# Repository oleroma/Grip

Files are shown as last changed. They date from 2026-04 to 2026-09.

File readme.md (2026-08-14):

<h1 align="center">
  <picture>
    <source media="(prefers-color-scheme: dark)" srcset="./media/logo_light.svg">
    <source media="(prefers-color-scheme: light)" srcset="./media/logo_dark.svg">
    <!-- The fallback image for older browsers -->
    Project Title
  </picture>
  <br>
</h1>

# GRIP
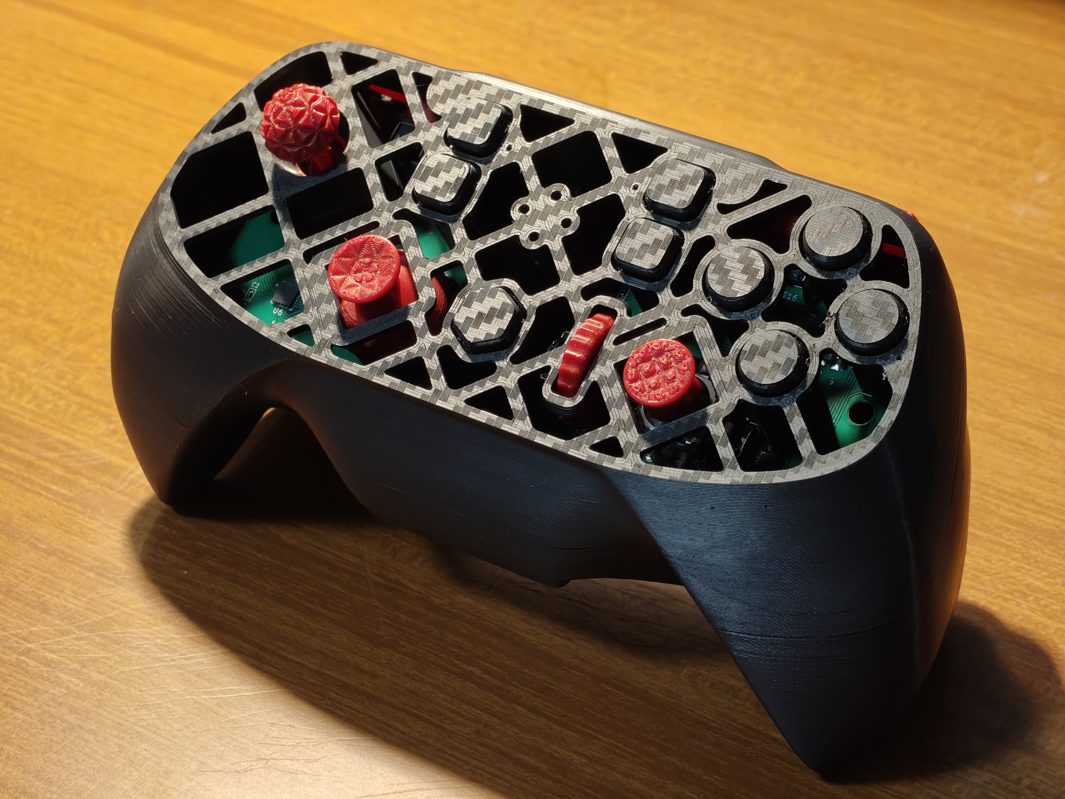
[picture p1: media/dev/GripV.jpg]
GripV


*(Work in progress... release coming soon)*

---

## **FEATURES AND PROGRESS**

### CASE SHAPES

The project will include the following **CASE SHAPES**: 
1. 2 smooth, classic shapes in Xbox and DualSense styles.
2. Custom ergonomic "pistol-like" shape.
3. SNES-style shape for portability (bonus shape).
4. Experimental custom ergonomic "pistol-like" shape with compliant bumpers L1R1 (will be released as experimental; currently exhibits cursor jumping).

> **NOTE:** You can easily swap the case for your own custom shape by placing your mesh into the corresponding "basemesh" collection—just drop it into the collection, and it will automatically be sliced and cut.

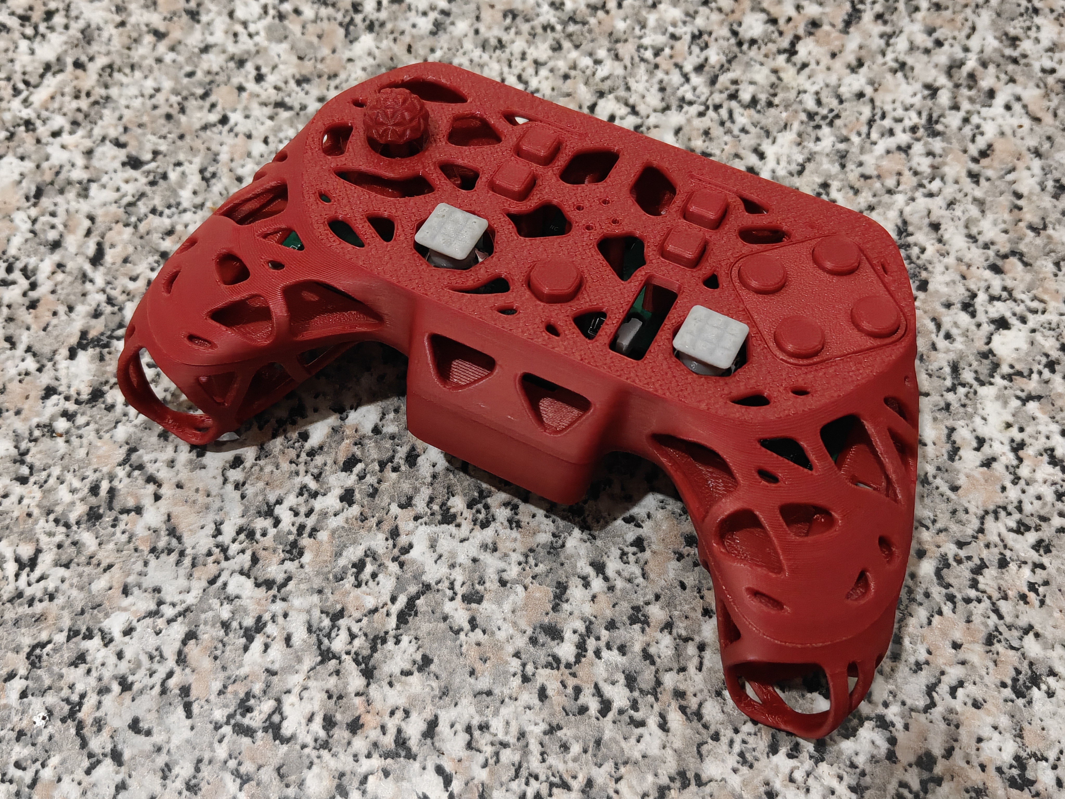
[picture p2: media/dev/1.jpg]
GripX


### HORIZONTALLY PRINTED BUTTONS

By default, the custom ergonomic shape (and possibly the classic shape) will use horizontally printed buttons with caps, as they provide a better feel, tighter tolerances, and less squeak. 

### FULL-SIZE RIGHT STICK

A great advantage of horizontal buttons is that when used with caps, their shafts are much smaller. Combined with a thinner scroll wheel and a new custom wheel support, this allows for a **FULL-SIZE RIGHT STICK** with a shield. This means you can have identical left and right sticks.

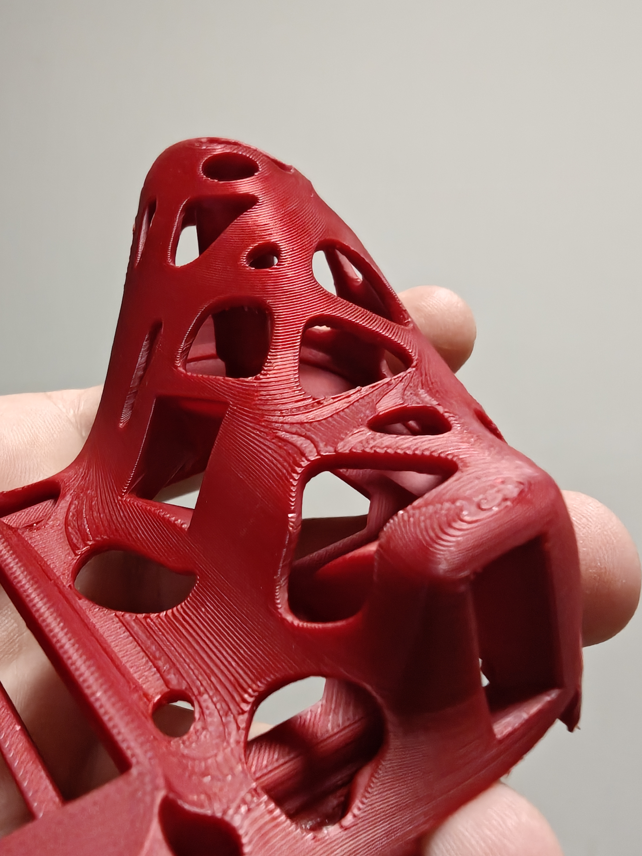
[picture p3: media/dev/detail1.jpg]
detail


### ADJUSTABLE TRIGGERS

Arch shaped triggers for L2R2 L4R4 do not require any screws to work and can be adjusted to fit different hands.

### **PROCEDURAL SHELL OPTIONS**

All shapes will come with an optional "hollow" version (made using Signed Distance Fields, or SDFs) that can be either a shell-like structure or a lattice-like structure with holes.

* **Hollow Version:** A 3-part assembly consisting of a top case, a bottom case, and a middle plate that holds the PCB. 
* **Solid Version:** Includes optional grip texturing featuring **periodic surface patterns** such as: Gyroid, Cubic, Primitive, Diamond, Voronoi, and Fischer-Koch S/CY.

### **NO-SCREWS OPTION**

The solid version is designed to be held together with screws. The hollow version does not require screws for assembly, though you can still have them if preferred.

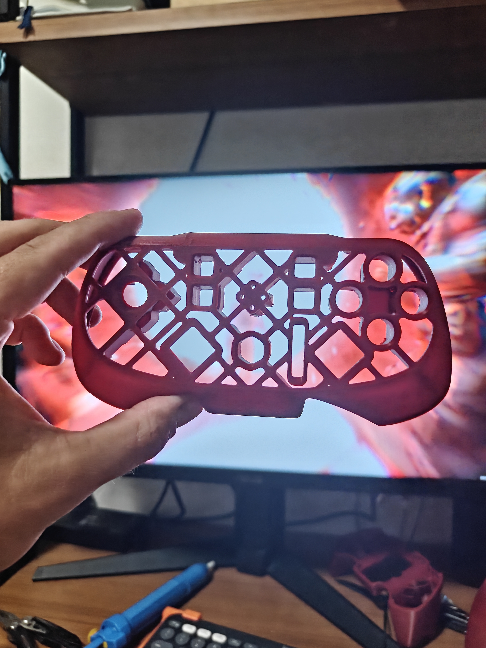
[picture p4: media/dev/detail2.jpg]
detail


### **PRINTING**

The project is optimized for FDM 3D printers, but it is also suitable for SLS and SLA printing—especially the hollow version.

### BLENDER PROJECT WITH NODES

The final **BLENDER** project, built with **GEOMETRY NODES**, will be released and will feature **PROCEDURAL GENERATION** for:

1. **Buttons:** Vertically or horizontally printed (very smooth, much quieter, less squeaky, and with tighter tolerances) with snap-on **caps**. Features customizable tolerances, **cap shapes** (want star- or heart-shaped buttons? You can have any shape!), and custom button logos (easily add any letter or symbol to the top of your buttons).
2. **Sticks:** Customizable range (specify the maximum tilt angle), size, height, stick-top shape, and cutout hole (circle, square, hexagon, or octagon). Also features customizable top texture and profile (convex, concave, or flat; square or circle).
3. **Bumpers (L1/R1):** Tunable size, shape, tolerances, and dimensions (width, height, and depth of the button).
4. **Arch-Shaped Triggers (L2/R2, L4/R4):** Tunable size, shape, positions, press angles, and tolerances (**no screws required**). You can move them inward, outward, up, or down to match your exact fingertip resting positions.
5. **Battery Cover:** Customizable battery compartment size, thickness, etc.
6. **Scroll Wheel:** Customizable diameter and width.

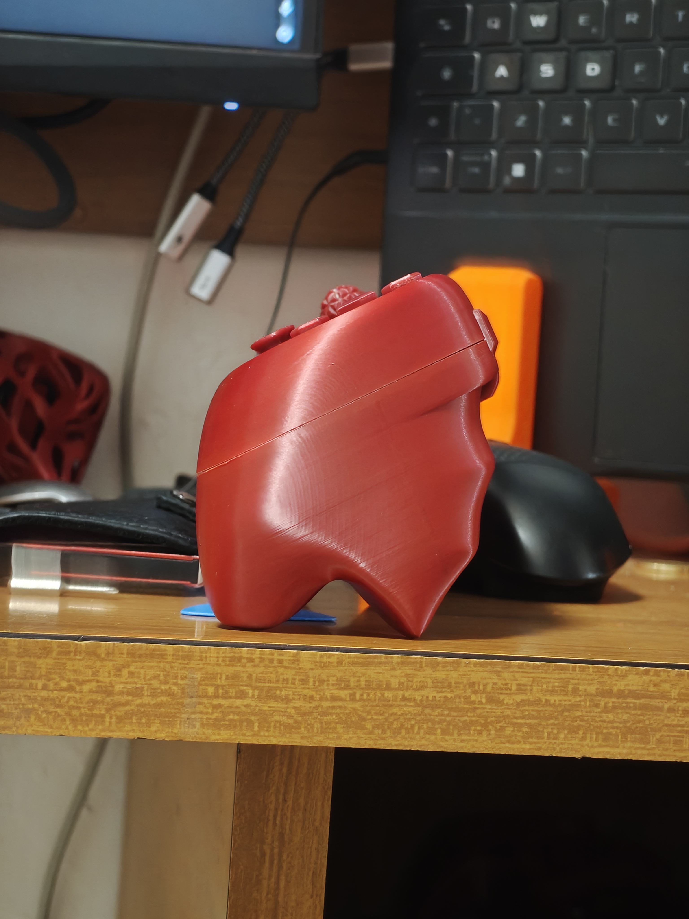
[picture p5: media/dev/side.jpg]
side


### **RELEASE PLAN**

All versions will be released as separate `.3mf` files for OrcaSlicer, along with `.stl` files. Releases will roll out as soon as testing is complete, starting with the solid versions and progressing to the more complex models.

---

## **CURRENT STATE**

Everything is functional, assembles properly, and fits well.

* **Solid Version:** 90% complete. Currently fine-tuning case shapes and button positions.
* **Hollow Version:** 80% complete. Currently fine-tuning assembly tolerances.
* **Blender Project:** 80% complete. The underlying logic is robust and functional. The UI is still a bit messy and may feel overwhelming due to the large number of parameters. Need to polish the layout and create simplified controls for frequently used parameters (e.g., tolerances and trigger positions).

---

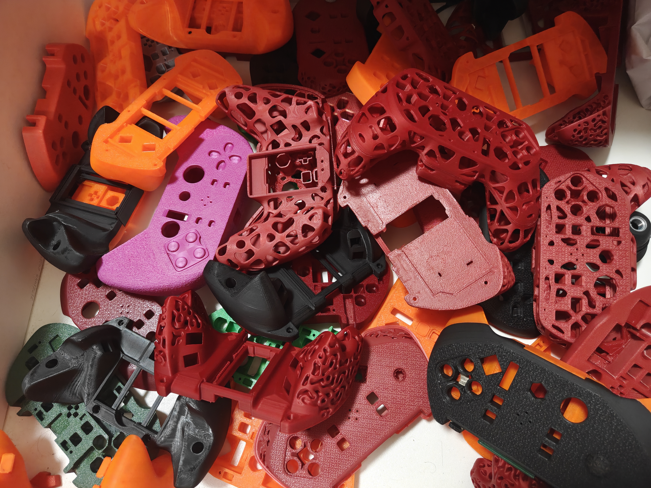
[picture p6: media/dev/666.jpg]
goobiewoobies


## **TO DO**
 
1. Create documentation and a video guide on printing, cleaning, and assembly.
2. Create `.3mf` files for each version.
3. Polish the `.blend` project UI.

# **NOTE:** The initial release will be a **beta**. If you are willing to be a tester, please let us know!

**Credits:** Oleroma, Milwud

---

## **DEPENDENCIES**
* Git LFS
* Blender >= 4.x

## **LFS AND FILE DOWNLOAD**

If you want to download the Blender and STL files, **DO NOT USE the "Download ZIP" button** on GitHub. It is not compatible with LFS (Large File Storage). Instead, please clone the repository directly.

To use Git with this project, you must first install [Git Large File Storage](https://git-lfs.github.com).

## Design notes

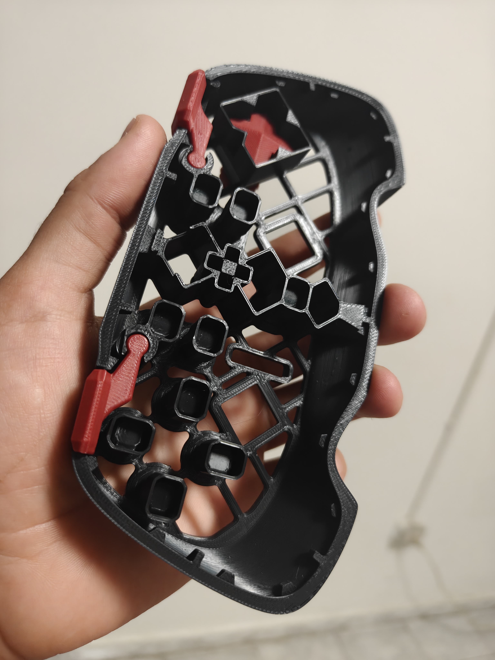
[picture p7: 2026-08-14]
media/dev/GripV_top.jpg

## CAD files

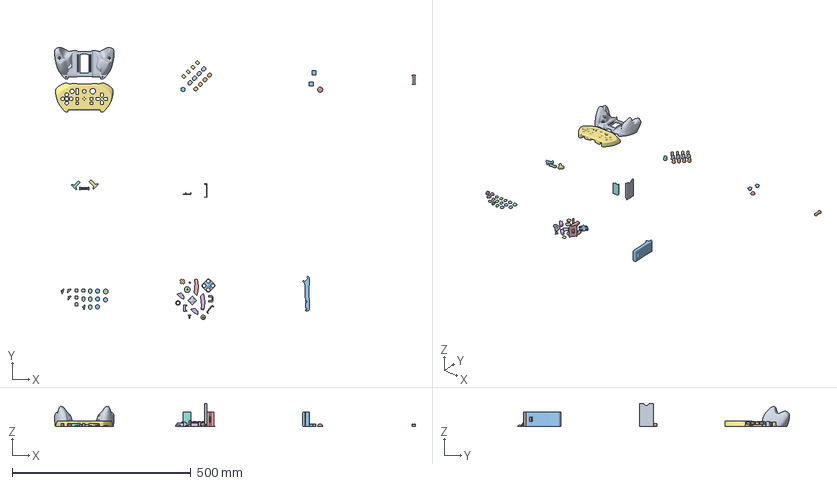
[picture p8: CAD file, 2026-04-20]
orca_bambu_A1_default/gripR1.3mf
1009.7 x 761.5 x 65.3 mm
case_bottom
fix.stl
capacitive_plate.stl
home_cap.stl
R4.stl x 2
case_top
BACK_CLIP.stl
rocker.stl
Wheel_holder.stl
abxy_cap.stl x 4
Wheel.stl
USB_CLIP.stl
R2.stl x 2
R1.stl
L1.stl
cable_holder.stl
rocker_support.stl
StickL.stl
dpad_cap.stl x 4
dpad_stick_cap.stl
ball_support.stl
rocker_ball.stl
Wheel_core.stl
battery_cover.stl
stick.stl
StickR.stl
select_cap.stl x 4
R4_tip.stl x 2
R2_tip.stl x 2
select_button.stl x 4
home_button.stl
dpad_button.stl x 4
abxy_button.stl x 4
phone_holder_mount.stl
flex.stl

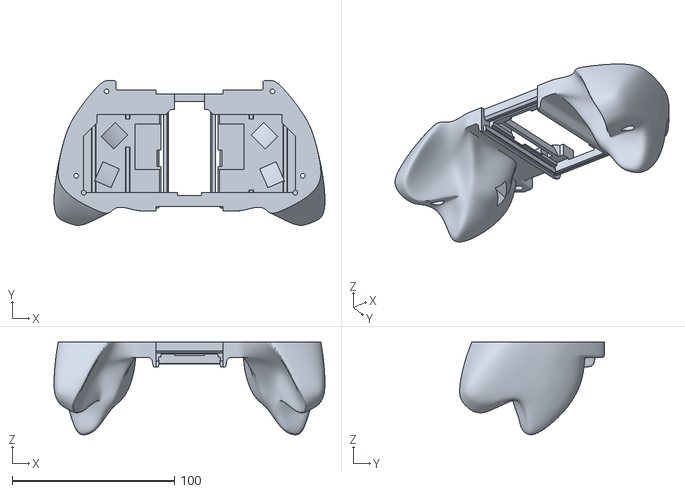
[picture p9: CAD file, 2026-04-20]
orca_bambu_A1_default/stl/case_bottom.stl
166.9 x 89.2 x 57.1

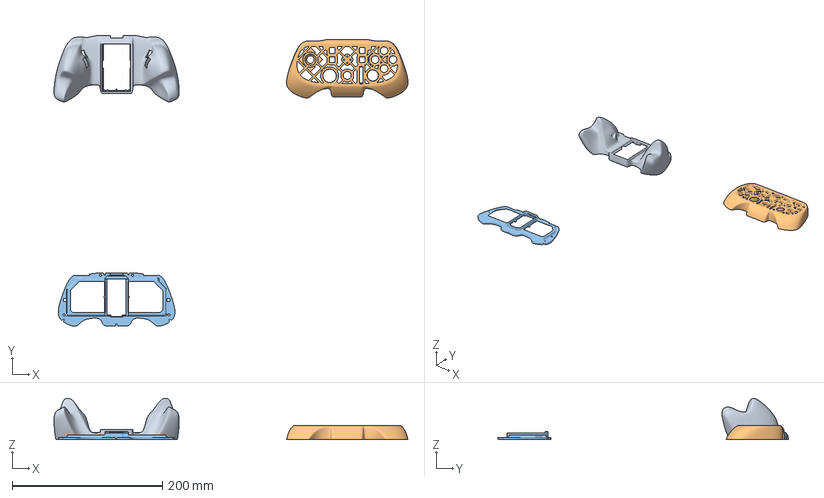
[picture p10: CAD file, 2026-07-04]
orca_bambu_A1_GripV_shell/GripV_shell.3mf
471.4 x 386.9 x 55.2 mm
case_bottom.stl
case_top
case_middle_plate.stl

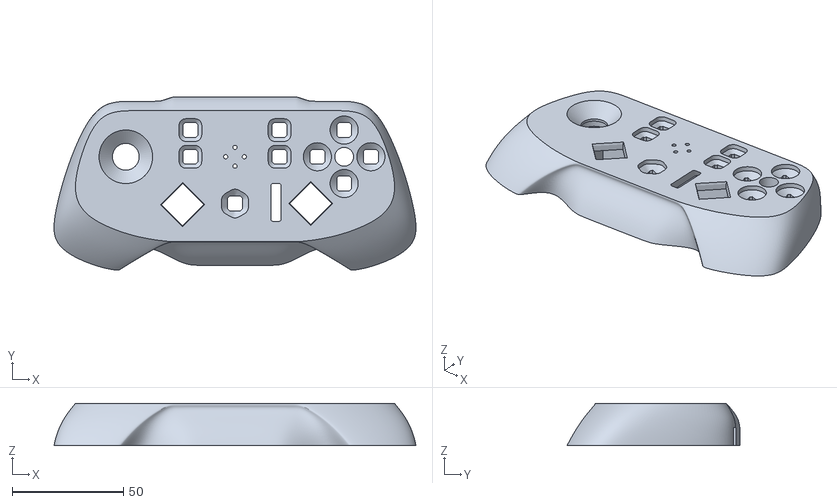
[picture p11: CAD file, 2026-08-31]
orca_slicer/bambu_A1/GripV/case/case_solid_olex/case_top.stl
162.5 x 77.7 x 19.0

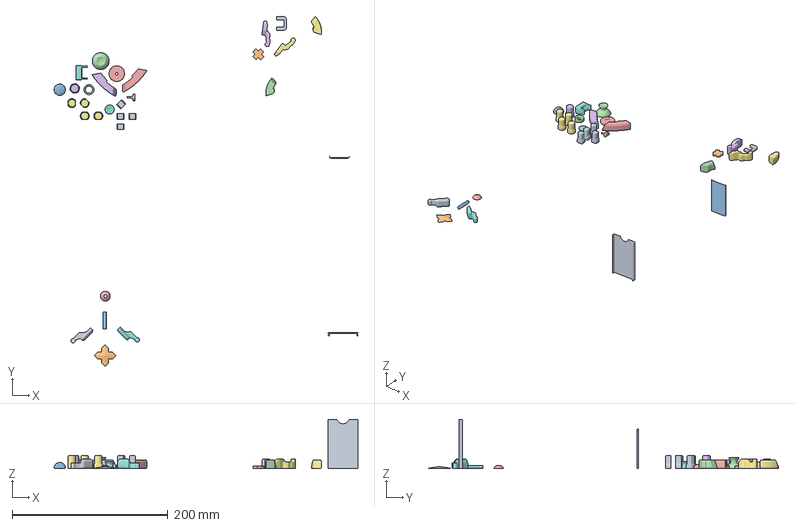
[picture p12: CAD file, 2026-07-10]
orca_slicer/dongle_case/GripV_shell_dongle_case.3mf
390.7 x 450.1 x 63.1 mm
battery_cover.stl
rocker.stl
marmota_secure.stl
StickL.stl
Wheel.stl
R1.stl
L1.stl
cable_holder.stl
Wheel_holder.stl
rocker_support.stl
dpad_stick_cap.stl
ball_support.stl
rocker_ball.stl
home_button.stl
abxy_button.stl x 4
StickR.stl
select_button.stl x 4
Wheel_core.stl
stick.stl
R2.stl x 2
R4.stl x 2
L1_lever.stl
R1_lever.stl

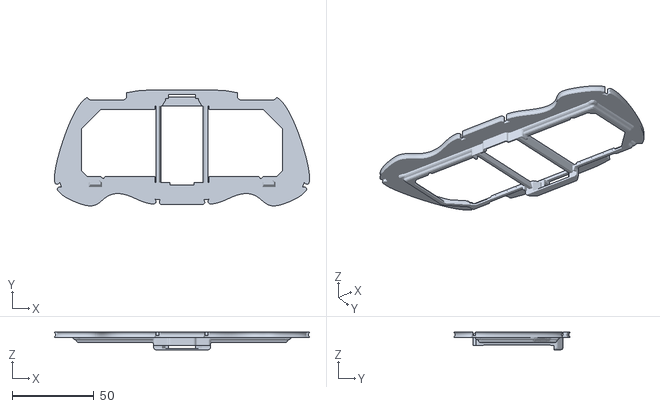
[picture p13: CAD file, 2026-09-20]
orca_slicer/GripV/case_hollow/case_middle_plate.stl
156.3 x 71.0 x 10.8

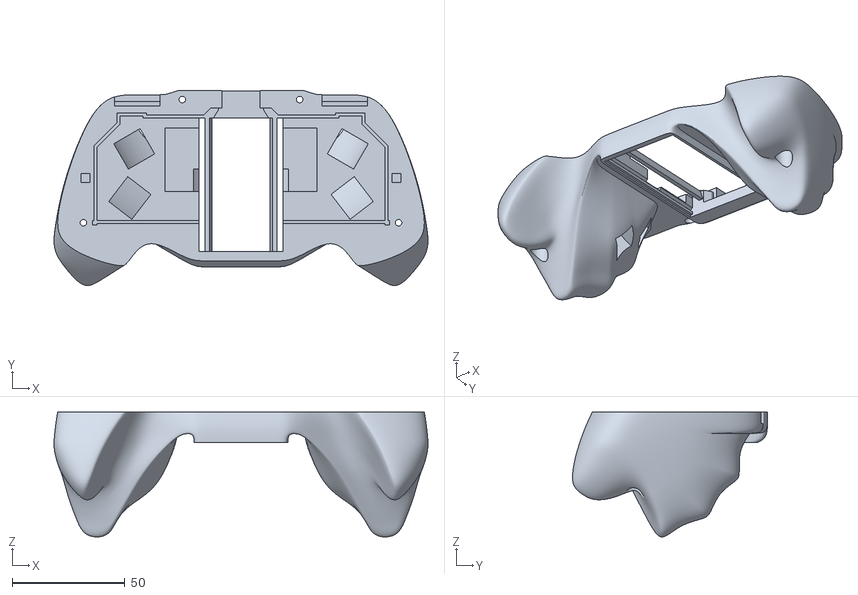
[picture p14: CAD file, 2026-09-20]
orca_slicer/GripV/case_standard/case_bottom.stl
165.8 x 86.5 x 55.4

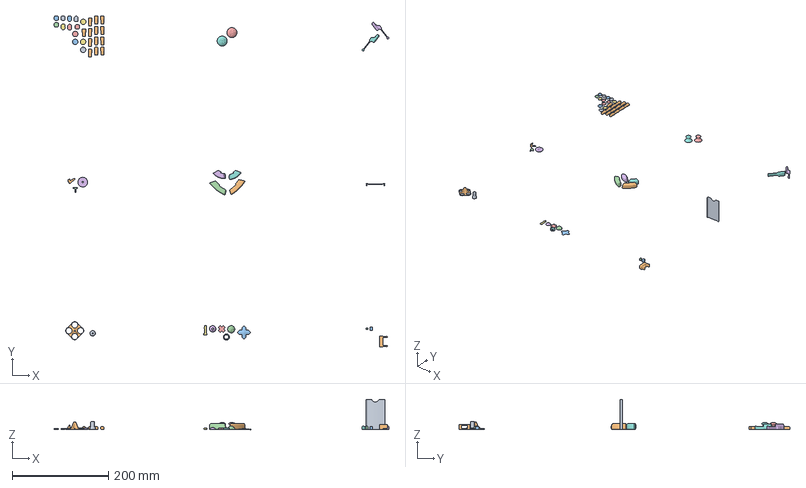
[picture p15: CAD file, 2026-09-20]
orca_slicer/GripV/GripV_parts.3mf
694.0 x 686.5 x 63.1 mm
battery_cover.stl
abxy_button.stl x 13
rocker.stl
dpad_stick_cap.stl
rocker_support.stl
rocker_ball.stl
stick.stl
ball_support.stl
capacitive_knob.stl
cable_holder.stl
nut_lock.stl
pin.stl
StickL.stl
scrollwheel.stl
abxy_cap_right.stl
StickR.stl
abxy_cap_left.stl
scrollwheel_holder.stl
abxy_cap_up.stl
scrollwheel_core.stl
abxy_cap_down.stl
L1.stl
home_cap.stl
R1.stl
dpad_cap_left.stl
R4.stl
dpad_cap_right.stl
L4.stl
dpad_cap_down.stl
R2.stl
dpad_cap_up.stl
L2.stl
select_cap_top_right.stl
capacitive_plate.stl
select_cap_top_left.stl
select_cap_down_left.stl
select_cap_down_right.stl

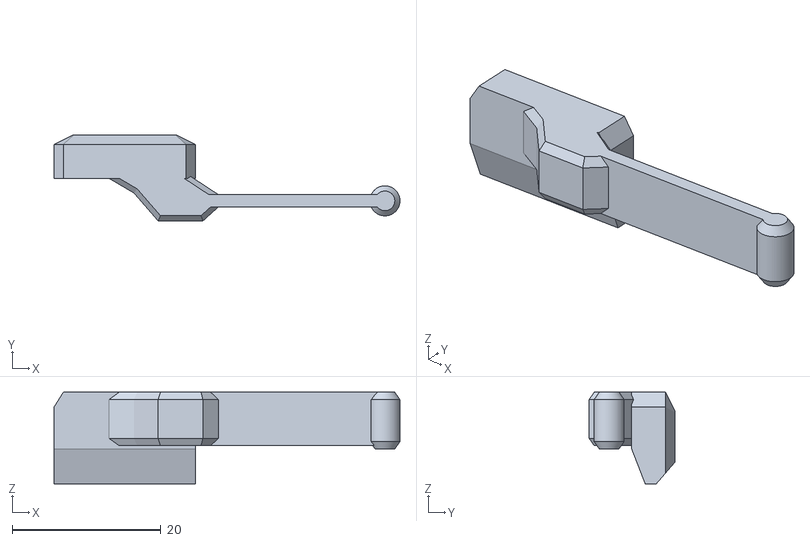
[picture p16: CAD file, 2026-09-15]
orca_slicer/GripV/parts/bumpers/press_default/L1.stl
46.5 x 11.5 x 12.3

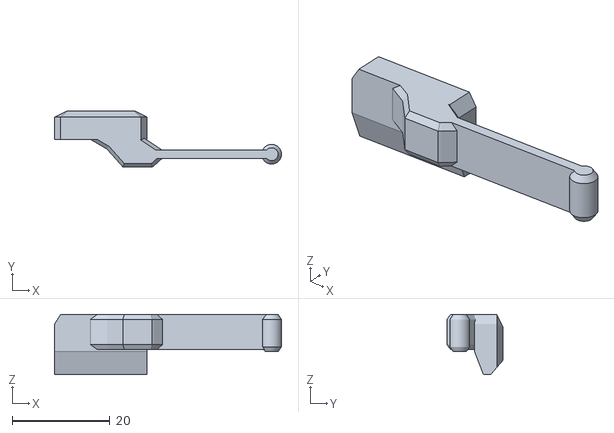
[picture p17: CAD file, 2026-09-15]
orca_slicer/GripV/parts/bumpers/press_loose/L1.stl
46.5 x 11.4 x 12.3

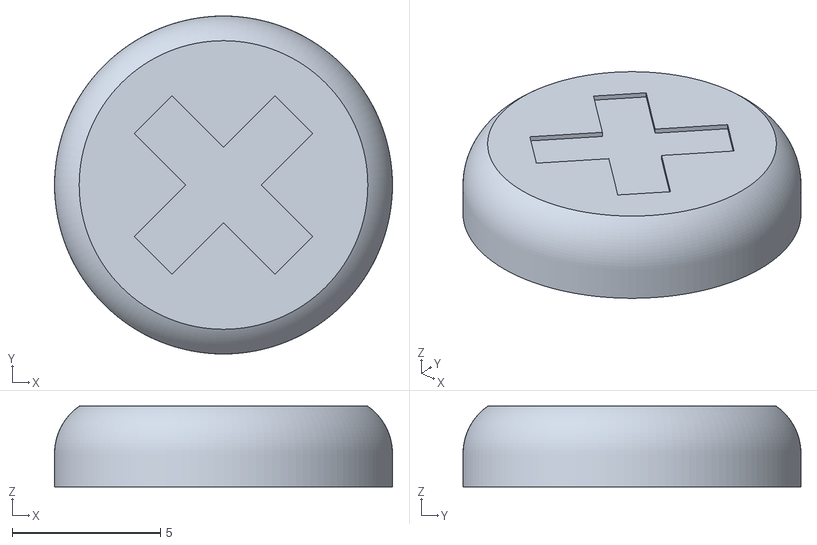
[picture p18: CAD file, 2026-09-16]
orca_slicer/GripV/parts/buttons/default/caps_default/abxy_cap_down.stl
11.4 x 11.4 x 2.72

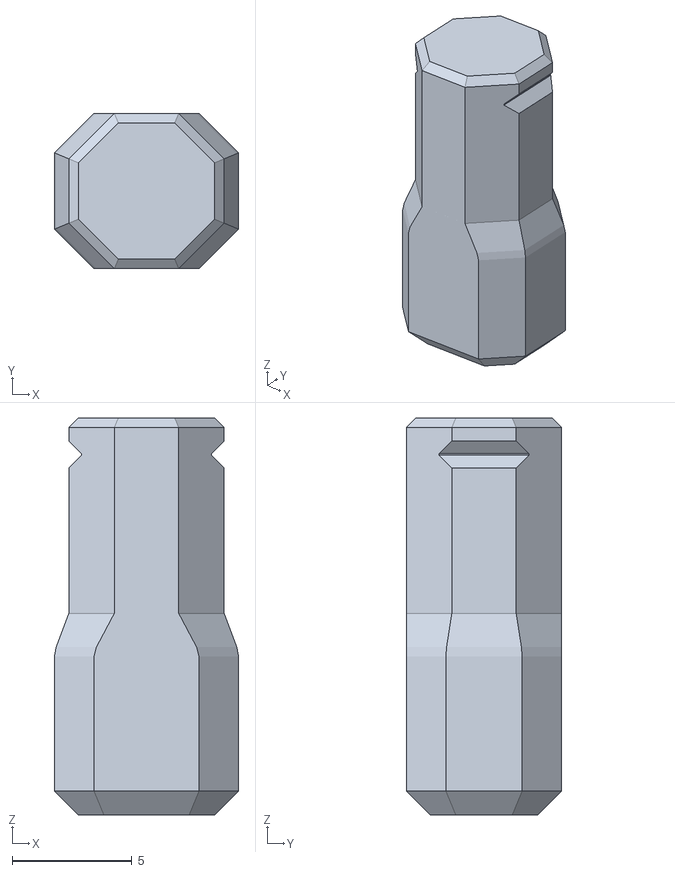
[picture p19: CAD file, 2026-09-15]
orca_slicer/GripV/parts/buttons/default/select_button.stl
7.68 x 6.48 x 16.6

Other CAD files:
orca_slicer/GripV/parts/bumpers/press_tight/R1.stl
orca_slicer/GripV/parts/bumpers/R1_pr_tight.stl
orca_slicer/GripV/parts/buttons/default/caps_loose/abxy_cap_down.stl
orca_slicer/GripV/parts/buttons/default/caps_tight/abxy_cap_down.stl
orca_slicer/GripV/parts/buttons/loose/caps_default/abxy_cap_down.stl
orca_slicer/GripV/parts/buttons/loose/caps_loose/abxy_cap_down.stl
blender/Grip.blend
blender/ref.blend
orca_slicer/GripV/GripV_case_hollow.3mf
orca_slicer/GripV/GripV_case_standard.3mf
orca_slicer/GripV/GripV_case_za3tarani.3mf
orca_slicer/GripV/parts/StickL.stl
orca_slicer/GripV/parts/StickR.stl
orca_slicer/GripV/parts/battery_cover.stl
orca_slicer/GripV/parts/bumpers/L1_pr_tight.stl
orca_slicer/GripV/parts/bumpers/R1_pr_default.stl
orca_slicer/GripV/parts/bumpers/R1_pr_loose.stl
orca_slicer/GripV/parts/bumpers/press_default/R1.stl
orca_slicer/GripV/parts/bumpers/press_loose/R1.stl
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

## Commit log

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2025-10-23 screw bool rework
    [basemesh.blend, case_back.blend, case_front.blend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]
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2025-12-21 cap plate by default
    [Capacitive_plate.001.stl, Capacitive_plate.stl, abxy_caps.001.stl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]
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2025-12-23 R1L1 fix
    [R1fix.stl, gripR1.3mf, trigger_R1.blend]
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2026-02-27 merged all .blend files into single one
    [basemesh.blend, buttons.blend, case_back.blend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]
2026-03-02 trigger rework
    [Capacitive_plate.stl, L1.stl, R1.stl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]
2026-03-03 huge rework
    [Capacitive_plate.stl, L1.stl, R1.stl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]
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2026-03-06 print test. flex. dpad stick is on.
    [L1.stl, R1.stl, abxy_button.stl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]
2026-03-06 print test. comfy pinky.
    [R2.stl, R2_tip.stl, R4.stl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]
2026-03-06 print test. comfy pinky.thicker grip
    [case_bottom.stl, case_top.stl, gripR1.3mf]
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2026-03-07 small fix to r2r4 logic
    [L1.stl, R1.stl, flex.stl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]
2026-03-07 flex enabled by default
    [flex.stl, flex_petg.3mf, gripR1.3mf]
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2026-03-09 R2R4 changed size and position
    [R2.stl, R2_tip.stl, R4.stl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]
2026-03-10 clean up, added variant 1 folder
    [BACK_CLIP.stl, L1.stl, R1.stl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]
2026-03-11 all button tolerance to 0.2, clip tune
    [BACK_CLIP.stl, USB_CLIP.stl, abxy_button.stl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]
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2026-03-11 variant 1 rework
    [BACK_CLIP.stl, L1.stl, R1.stl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]
2026-03-11 tuned wobble in dpad stick and wheel, tuned r2r4 geometry, adjusted pcb z tolerance logic, increaced r2r4 stopper height, changed r2r4 stopper logic, r2r4 would probably require tuning
    [R2.stl, R2_tip.stl, R4.stl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]
2026-03-11 cleanup, tolerance increace
    [R2.stl, R2_tip.stl, R4.stl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]
2026-03-11 button smd fix
    [abxy_button.stl, dpad_button.stl, gripR1.3mf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]
2026-03-11 dpad stick and wheel support fix
    [Wheel_holder.stl, gripR1.3mf, gripR1_variant1.3mf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]
2026-03-12 added thickness in cover area, increased reinforcer size
    [BACK_CLIP.stl, USB_CLIP.stl, abxy_button.stl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]
2026-03-13 cleanup and fixes
    [BACK_CLIP.stl, L1.stl, USB_CLIP.stl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]
2026-03-13 variant 1 screws to 12 mm
    [case_bottom.stl, case_top.stl, gripR1_variant1.3mf]
2026-03-13 fixes, tolerances
    [R4.stl, R4_tip.stl, abxy_button.stl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]
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2026-03-21 small cap plate fix
2026-03-22 basemesh and wire cutout fixes, R4 changes, stick tweaks
2026-03-23 pcb fix
2026-03-25 face button tolerance adjustments
2026-03-25 stick shaft tolerance adjustment
2026-03-25 tweaked pin tolerances
2026-03-25 battery compartment fixes
2026-03-29 stick variant added, adjustments to right stick, other buttons tolerance adjustments
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2026-04-03 var1 fixes
    [case_top.stl, gripR1_variant1.3mf]
2026-04-03 some fixes, some work on phone holder
    [USB_CLIP.stl, gripR1.3mf, home_button.stl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]
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2026-04-04 usb inner bool adj
    [gripR1.3mf]
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2026-04-19 select button error fix
2026-04-19 modified battery wire cutout. swapped files
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2026-04-20 some work, pcb cutout adj
    [BACK_CLIP.stl, L1.stl, R1.stl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]
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2026-06-16 test GripV bottom case
    [L1.stl, R1.stl, R2.stl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]
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2026-06-22 Hollow Shell test 1
    [GripV.3mf, GripX.3mf, GripX_shell.3mf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]
2026-06-24 GripX shell test 2
    [GripX_shell.3mf, StickL.stl, StickR.stl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]
2026-06-26 GripV shell test 1
    [GripV_shell.3mf, case_middle_plate.stl]
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2026-06-29 GripV shell test 2
    [GripV_shell.3mf, case_middle_plate.stl]
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2026-07-15 fixed sticks, pcb wire cutout, fixed gripx basemeshes at battery cutout area
    [gripr1.blend]
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2026-07-16 fixed addon
    [Grip.blend, case_middle_plate.stl]
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2026-07-18 addon fix
    [Grip.blend, case_middle_plate.stl]
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2026-07-22 couple fixes
    [Grip.blend]
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2026-07-24 horizontal buttons improved bevel tolerance
    [Grip.blend]
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2026-07-25 reworked R1 shape, some tolerance adjustments for all triggers
    [Grip.blend]
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2026-08-01 fixes, full size sticks
    [Grip.blend, GripV_buttons_horizontal.3mf, L1.stl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]
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2026-08-02 wip, hollow patterned, refine, pretty and fixes
    [Grip.blend]
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2026-08-04 stick correction
    [Grip.blend, GripV_case_hollow.3mf, case_middle_plate.stl]
2026-08-04 stick fixes
    [Grip.blend]
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2026-08-04 button tolerance fixes for solid case
    [Grip.blend]
2026-08-04 pin fix
    [Grip.blend]
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2026-08-06 caps and trigger improvements, fixes
    [Grip.blend, GripV_buttons_horizontal.3mf, GripV_case_hollow.3mf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]
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2026-08-07 R2R4 cutout slight adjustment, refine and conform to 0.16 layerheight for GripV
    [Grip.blend, GripV_buttons_horizontal.3mf, GripV_case_hollow.3mf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]
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2026-08-09 trig fix
    [Grip.blend, L1.stl, R1.stl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]
2026-08-09 trigger fix
    [Grip.blend]
2026-08-10 triggers, old values alongside with new one, configurable, action
    [Grip.blend, GripD_case_solid.3mf, GripV_parts.3mf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]
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2026-08-10 caps fix
    [Grip.blend, GripD_case_solid.3mf, GripD_parts.3mf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]
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2026-08-11 fixed R2 getting stuck, tolerance adjustments
    [Grip.blend]
2026-08-11 old cap plate depth, small fixes
    [Grip.blend, GripV_parts.3mf, battery_cover.stl]
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2026-08-14 dpad stick wip, pcb middle supports battery height reduced (to be closer to marmota to prevent detachment while playing in wired mode)
    [Grip.blend, GripV_case_hollow.3mf, GripV_parts.3mf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]
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2026-08-14 button logos wip, fill fixes
    [Grip.blend]
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2026-08-18 pillars fix, R1L1 flex for hollow wip
    [Grip.blend]
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2026-08-23 tolerance management system
    [Grip.blend]
2026-08-24 fixes, pretty
    [Grip.blend, GripV_buttons.3mf, GripV_case_hollow.3mf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]
2026-08-24 tolerance, trigger and stick fixes, again
    [Grip.blend]
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2026-09-05 all trigger and button tolerance adjustments - hopefully final, sticks Z fixes
    [Grip.blend]
2026-09-06 Grip D screw position fixes
    [Grip.blend]
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2026-09-12 tolerance set inputs exposed
    [Grip.blend]
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2026-09-15 middle plate fix
    [Grip.blend]
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2026-09-16 fix hollow top
    [Grip.blend]
2026-09-17 left stick fixes
    [Grip.blend]
2026-09-17 last left stick variant fix
    [Grip.blend]
2026-09-17 hollow slight bumper redesing, align pin and support placement
    [Grip - Copy.blend, Grip.blend, GripV_case_hollow.3mf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]
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2026-09-20 extension update, cleanup for release, stick grid texture fix
    [Grip.blend, GripV_case_hollow.3mf, GripV_case_standard.3mf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]
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2026-09-21 small fix
    [Grip.blend]
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2026-09-24 select caps fixes
    [Grip.blend]
2026-09-24 reinforcer to offset
    [Grip - Copy.blend, Grip.blend]
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2026-09-27 select cap fixes, back screw adjustments
    [Grip.blend]
2026-09-27 home cap fix
    [Grip.blend]
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2026-10-01 elite 2 stick base fix
    [Grip.blend]
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2026-10-13 Add orca_reload: batch Reload from disk for OrcaSlicer projects
    tools/orca_reload/orca_reload.py updates every STL-sourced part in one or
    more OrcaSlicer .3mf projects from the STL files on disk, the same way
    Orca's Reload from disk does: the new mesh keeps the old bounding-box
    centre, orientation and plate placement stay, and the object is dropped
    back onto the bed unless it was sunk. Settings, plates and every other
    file in the project are copied unchanged. Output goes to a new file and
    the original is never overwritten. Missing or ambiguous STLs are reported
    and left as they were.
    Standard library only, so Blender's bundled Python can run it. Includes a
    README and unit tests that build O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
2026-10-13 Document Grip.blend in docs/blender
    Add a documentation set for blender/Grip.blend: a file tour, the
    parameter system, global switches, variants, the case, body types,
    tolerances, export and tracking, a page per part, an issues list, an
    editing guide and the method. Reference tables (preset values,
    constructor groups, node group catalogue, measurements) are generated
    from the file at 571e768. Link it from the readme.
    Claude-Session: https://claude.ai/code/session_01RGVqqHJhZz6BUXtkMB1f67
2026-10-13 Restructure Grip.blend docs into two guides
    Replace the data-heavy documentation with two guides: one for people
    who customize and export parts (what each setting changes in the
    design, where to find it, how to export), and one for contributors
    (how the file and node trees are built and what each structure
    achieves). Drop the cross-section images, generated value tables,
    measurement dumps and the method page; current values are tracked in
    blender/tracking.json.
    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
2026-10-13 FIXED "The GripX “Parts” preset switches the capacitive part through GripV abxy"
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2026-10-14 Add a script that writes tooltips for global and fit parameters
    scripts/apply_tooltips.py sets the description of 187 inputs on
    global parameters, tolerance set and the constructors that decide fit
    (buttons and caps, triggers, bumpers, sticks, battery cover, pins,
    scroll wheel, PCB slot, capacitive plate). Texts follow the customize
    guide. It changes no value, link or name, and reports missing or
    renamed inputs. Run it in Blender on Grip.blend, then save.
    Claude-Session: https://claude.ai/code/session_0178k4VJytzhnes5KkLyY3nP
2026-10-14 Tidy GripX export file names and refresh the export docs
    - Rename the six GripX part files that still had spaces to the names
    the exporter writes (battery_cover.stl, dpad_stick_cap.stl, ...),
    as d478402 did for GripV.
    - Move GripX/Xbox_style/triggers into GripX/xbox_style/triggers. The
    preset writes xbox_style; the capital-X copy showed up as a second
    folder on GitHub and Linux.
    - Docs: mark the capacitive preset bug and the file name problem as
    fixed, note that the committed GripX capacitive_knob.stl still needs
    a re-export, and record that GripV now exports the scroll wheel and
    nut lock.
    Claude-Session: htt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
2026-10-14 Give beta testers a way in: getting started table and fit report form
    - README: a short 'Getting started' table pointing to the printing
    guide, the customize guide and the contributor guide; the beta note
    now links to a fit report; a not-affiliated note for the Xbox and
    DualSense names.
    - Issue forms: 'Fit report' (shape, printer, filament, tolerance
    folders printed, how each part fit) and 'Problem'.
    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
2026-10-15 Cover every tracked constructor in apply_tooltips and survive the typo cleanup
    Add tooltips for the remaining constructors that tracking.json records:
    marks parameters, grid and icosahedron texture parameters, dpad stick
    parameters, pins postion, screw parameters, screw position, the Index of
    the GripV/GripX screw presets, hollow parameters, top face parameters and
    middle plate parameters (115 new entries, 302 in all). Inputs listed as
    having no effect in known issue C4 get "Not used."; inferred texts are
    marked "# guess".
    When a group or input is not found, the script now tries its corrected
    spelling (wdith, heght, stiick, sheild, sbdiv; paramters, paramteters,
    postion, contols; spaces co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
2026-10-15 Add check_tooltips.py: check the tooltip table against tracking.json
    Plain Python, no Blender. It imports the table with a stand-in bpy module,
    checks that every group and input in TOOLTIPS exists in tracking.json
    (tracked values or Group Input links in all_node_trees), and prints the
    coverage of every tracked group. --cleanup checks against the names after
    the planned typo cleanup and lists what only matches through the
    corrected spelling. Exit status 1 on a stale entry, an input without a
    tooltip, an empty text or an em-dash.
    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
2026-10-15 Tighten four tooltip texts
    Pin X position mentions both mirrored holes, shell thickness says the
    lattice body does not read it (only the hollow group does), voxel remesh
    size says what it is, and the marks axis text reads more plainly.
    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
2026-10-15 Add fix_names.py: rename typo names in Grip.blend with a dry run
    Fixes misspelled words and stray spaces in node group names and group
    input names, renames group nodes that follow a renamed group, and
    rewrites every combi_export override that names a renamed group, node
    or input, in every scene. DRY_RUN (the default) only prints the table.
    Collisions and names stored where the script cannot update them safely
    (linked scenes, driver expressions, other add-on settings, combi_export
    disabled) are skipped and reported. Menu items, objects, collections,
    labels, panels, outputs and bundle items are only reported, as are text
    blocks that mention an old name.
    The tests build a fixture in memory wit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
2026-10-15 Point the D5 row at fix_names.py and add how to run it
    The note in known issues lists the steps: run on a copy saved next to
    Grip.blend, read the dry run, apply, compare exports before and after,
    save and check that tracking.json only renames keys. fix_names.py now
    reads the action slot's channels and looks up stored names in one pass.
    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
2026-10-15 Known issues D5: correct the GripR1 note and list the stray spaces
    GripR1 parameters is the live GripR1 variant parameter group, not a
    leftover; only the two-space GripR1 parameters is dead code (D3). The D5
    row now also names the stray spaces tracking.json shows (the voronoi
    hollow groups, euclidean distance, case cutout thickness), which
    fix_names.py fixes too, and that caps fit Z olerance is also an output of
    caps outputs. Step 6 says what tools/tracking_diff pairs as renamed.
    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
2026-10-15 Show input tooltips in the Grip tab and test lookups on the real wiring
    A plain socket field in the sidebar only shows Blender's generic
    tooltip. Each setting's name is now a flat button whose tooltip is the
    description of the group input, so the tooltips apply_tooltips.py
    writes into Grip.blend show in the tab too.
    New tests rebuild the preset groups of Grip.blend from the nodes and
    links recorded in blender/tracking.json and run the add-on's lookups on
    them: the live GripV trigger, both GripX styles behind the gripD switch,
    the live GripX cover, every GripX stick preset, and the inputs fed by
    tolerance sets or a Value node.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
2026-10-15 Grip tab: no "None" texts when the variant input is missing
    When 'global parameters' has no variant input, the Controller and Parts
    panels now say so plainly instead of printing None, and neither the
    mismatch warning nor the match button appears.
    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
2026-10-15 Add tracking_diff: a readable report of tracking.json changes
    tracking.json records every preset value, but commits often say only
    "sticks upd" and the JSON diff is hard to read. tools/tracking_diff lists
    the changes per controller, preset group and node: changed inputs as
    old -> new with the difference for numbers and vectors, added, removed
    and probably renamed inputs and nodes, edited basemeshes, and a short
    per-group summary of node wiring changes (raw links only with --verbose).
    A change to the shared global group is shown once for both panels.
    Compares commits (REF, A..B, A...B), files, or HEAD with the file on
    disk. --markdown writes tables for pull requests and job summaries, and
    --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
2026-10-15 Add build_release: print sets, release zips and a --check for orca_slicer
    print_sets.json lists, per released shape (GripV standard, GripV hollow,
    GripX xbox, GripX dualsense), which files to print and how many of each,
    with notes, conditions, unconfirmed quantities and parts that are not
    exported yet. build_release.py reads it to build one folder and zip per
    shape (default tolerance, --tolerance or --all-tolerances) with a
    generated PRINT_LIST.md and the license.
    --check works on Git LFS pointer files: every needed file exists, no
    spaces or case clashes in names, and it warns about tolerance variants
    and choices that are the same file (same LFS oid or content hash).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
2026-10-15 Document build_release and tidy its output
    README.md explains how to check and build a release, what each --check
    section means, how a build works and how to write print sets.
    The print list now shows a group condition once under its heading, a
    build that finds pointer files names five and counts the rest, and a
    tolerance folder at the top of the tree gives a clean pattern.
    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
2026-10-15 Add a print guide to orca_slicer: folders, tolerances and print lists
    orca_slicer/README.md is for people who just want to print: what each
    folder holds, how the case tops differ, the tolerance folders (start with
    default, reprint only the part that does not fit) and, per shape, every
    part with its quantity. Quantities that are not confirmed are marked, and
    the parts that are not exported yet are listed as known gaps.
    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
2026-10-15 build_release --check: catch case problems on Windows and macOS
    On a case-blind disk os.path.isfile found a file whose name differs
    from the print set only by case, so --check passed on Olex's machine
    while a Linux clone would miss the file, and two tracked names that
    differ only by case never showed up because the disk holds just one.
    --check and the build now compare names exactly, report the spelling on
    disk, and the name check also reads git's file list.
    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
2026-10-15 Print list: four corrections from tracking.json and the docs
    - GripV Home: caps flex cut differs from ABXY too, the same setting the
    D-pad note already flags as possibly shaping the clip on the shaft.
    - GripX case top: say which file is wrong (capacitive_knob.stl is still
    the plate), not the case top.
    - Known gaps: the GripX scroll wheel slot is a guess, as the print list
    row already says, and name the two settings that differ.
    - A cap that does not go on comes from cap_loose in its shaft's folder.
    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
2026-10-15 Add bill of materials and assembly guide drafts
    docs/bom.md lists the hardware a Grip build needs besides the prints:
    the Alpakka electronics (board, core module, switches, joystick
    modules, encoder, battery connector), the battery, the M2.5 screws and
    nuts, filament, cable and tools. Every row names its source (a Grip
    file, an Input Labs page or a guess); lengths and revisions that are
    not checked say "to confirm".
    docs/assembly-guide.md goes from cleaning the prints to closing the
    case, with what to check at each step and which tolerance folder to
    print when a part is tight or loose, plus notes for the hollow case.
    Inferred steps are marked unverified.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
2026-10-15 Print guide: point to the print list and the builder drafts
    "What to print" links the print list in orca_slicer/README.md for the
    files, quantities and tolerance table. The intro and "Still missing"
    now name the assembly guide and bill of materials drafts, what they
    still lack, and the parts that are not exported yet.
    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
2026-10-15 Customize docs: mention the Grip tab, fix the press folder note
    The guide index names the Grip tab in the workflow and in the page 1
    row. In Exporting, the folder spelling note now says what the files
    show: only the GripX bumpers use pres_* folders, the GripV bumpers and
    all triggers use press_*. The page also links the print list.
    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
2026-10-15 Builder drafts: match the sources on battery, connector, screws, bumpers
    - Battery and connector: the Input Labs pages name a PKCell 503562 with
    a "PH 2-pin" plug and a XUNPU WAFER-PH2.0 connector; they do not say
    LiPo or JST. Cite the components page for "optional, for wireless".
    - Back screws: GripX screw length is 25, not "just over 25".
    - Assembly step 6: only the GripX bumpers pivot on their stem; the GripV
    bumpers use the flex arm, as the Bumpers page says.
    - Step 8: "battery connector" instead of "JST connector".
    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
2026-10-15 Print list: every button uses the one exported shaft
    All button holes are the same for now, so button.stl is printed for every
    button, and the first release ships horizontal buttons only. Remove the
    Select, Home and D-pad shafts from the known gaps and the release check,
    and correct what fillet, fillet subdiv and caps offset change.
    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
2026-10-15 Grip.blend name and tooltip cleanup, known-issues status, new exports
    - Grip.blend: renamed node groups/inputs and tooltips; tracking.json follows
    (drops the unused "GripR1 parameters" group and the stale screws link)
    - 07-known-issues.md: Done and Resolution columns, A1/A2/A7/A8/A9/A11 closed
    - GripX bumpers: single press tolerance, L1/R1 moved out of pres_* folders
    - GripX capacitive_knob.stl re-exported (A2)
    - New exports: GripV case_middle_plate.stl, GripX scrollwheel parts
    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
2026-10-15 Print list and docs: GripV middle plate, GripX scroll wheel and bumpers exported
    The GripV middle plate and the GripX scroll wheel are now exported, the
    GripX capacitive knob is re-exported, and the GripX bumpers have one fit
    in <style>/bumpers/. Point the print sets and the print list there and
    drop those gaps from the known problems. --check: 0 errors, 4 warnings.
    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
2026-10-15 Grip.blend: PCB Z tolerance and below height fix, stem radius, known issues C1-C3/C5/C7
    Grip.blend / tracking.json (values)
    - GripV lever R1L1 > R1L1 lever parameters: stem radius 3.0 -> 2.0. The
    Value node that overrode it is no longer linked, so the input is now the
    live value (C1).
    - GripV pcb cutout parameters > PCB below height 1.76 -> 3.84 (+2.08, the
    GripV PCB thickness).
    - GripX pcb cutout parameters > PCB below height 1.92 -> 3.92 (+2.0, the
    GripX PCB thickness).
    - global parameters (GripV and GripX): subdivision level "low " -> "low",
    the trailing space is gone (C9 fixed in the file, not ticked yet).
    - GripX shell middle plate parameters: the disconnected duplicate node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
2026-10-15 Release builder: plain build leaves out the tolerance folders
    A build without flags holds only the default tolerance, so its tolerance
    folders and names are redundant. It now flattens them: parts/bumpers/
    press_default/ becomes parts/bumpers/, parts/buttons/default/cap_default/
    becomes parts/buttons/cap/, and GripV-standard-default.zip becomes
    GripV-standard.zip. flat_folders in print_sets.json sets the name each kind
    of tolerance folder gets ("" drops it).
    --full-paths keeps the old layout and names; --all-tolerances always does.
    A build stops, and --check reports an error, if two files would land on the
    same path without the tolerance folders.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
2026-10-15 Release builder: compare the print sets with what the combi_export presets export
    print_sets.json names the preset JSON files combi_export saves next to
    Grip.blend. --check warns about print-set files no preset exports and marks
    unused files the presets no longer write; a build warns about such files.
    Claude-Session: https://claude.ai/code/session_01FASWdPdj93xbtrLG4xwbs4
2026-10-15 Release builder: make the releases from the combi_export preset files alone
    print_sets.json is gone. The builder now reads blender/<scene>_preset.json,
    whose exports list every file the presets write, and derives the rest:
    each top folder of a scene folder other than parts/ is one shape, the
    OrcaSlicer projects are found by name, the tolerance folders by their names,
    and PRINT_LIST.md takes the scene's print list from orca_slicer/README.md.
    A plain build keeps the flat paths of PR #7.
    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
2026-10-15 Release builder: print lists follow the zips, catch parts the presets miss
    PRINT_LIST.md now drops the print-list rows of the other shapes, shows the
    zip paths, lists every folder that moved, and names any print-list path no
    preset exports, which --check and the build warn about. A part with no
    variant at a tolerance fails that build (and --check at default). Release
    ids that collide, a root folder spelt with another case, a repository path
    with brackets, unreadable or empty preset files, and uncommitted preset
    changes are handled.
    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
2026-10-15 Grip.blend: fix the GripV Case hollow and GripX Bumpers presets; preset files with the export lists
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2026-10-17 seam fix case standard
2026-10-18 stick variant switch fix
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
